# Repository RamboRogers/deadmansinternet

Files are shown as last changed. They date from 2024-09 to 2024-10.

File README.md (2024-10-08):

# Deadman's Internet

<p align="center">
  Full View
</p>

### A project by Matthew Rogers

Welcome to the **Deadman's Internet** project! My name is Matthew Rogers, and I'm passionate about creating practical, cost-effective solutions that solve real-world problems. You can learn more about my work on my [homepage](https://matthewrogers.org) or check out my other projects on my [GitHub profile](https://github.com/RamboRogers).

### Introduction

**Deadman's Internet** is a self-healing internet switch designed to ensure continuous connectivity by automatically resetting your network devices when a connection failure is detected. This project is ideal for anyone who experiences unreliable internet connections and wants a hands-off solution that keeps their network running smoothly without manual intervention.

The project is built around the affordable and powerful M5Stack AtomS3, making it both effective and budget-friendly, with a total cost of under $35.
| Online | Pinging | Cycling | Offline |
| --- | --- | --- | --- |
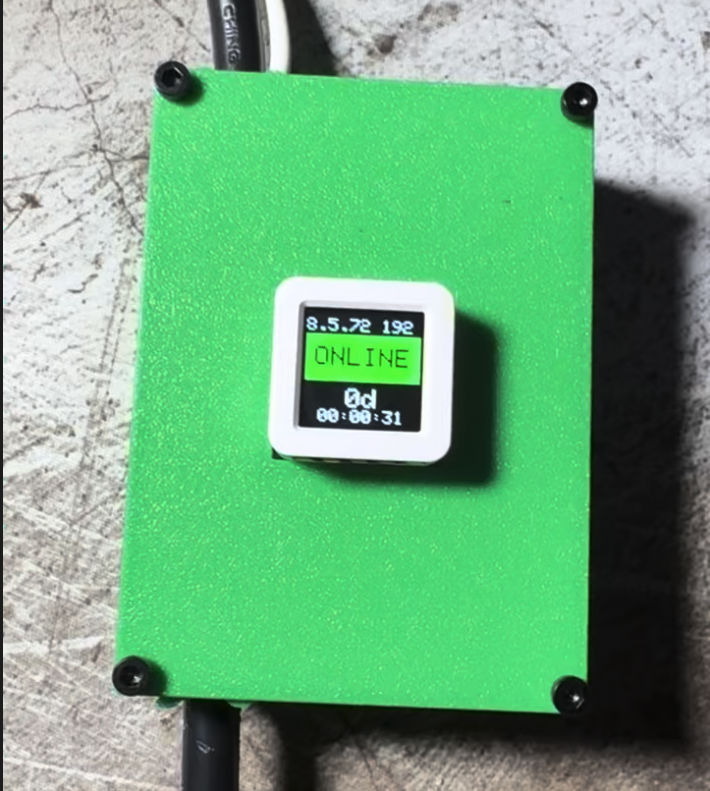
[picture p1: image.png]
Online
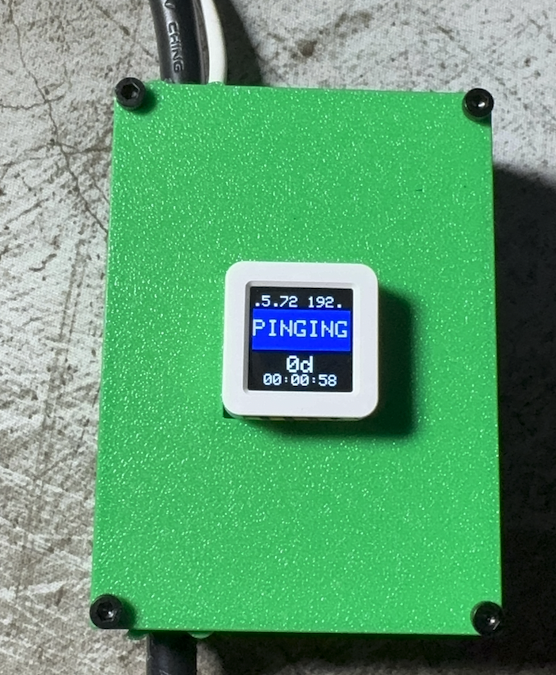
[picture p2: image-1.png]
Pinging
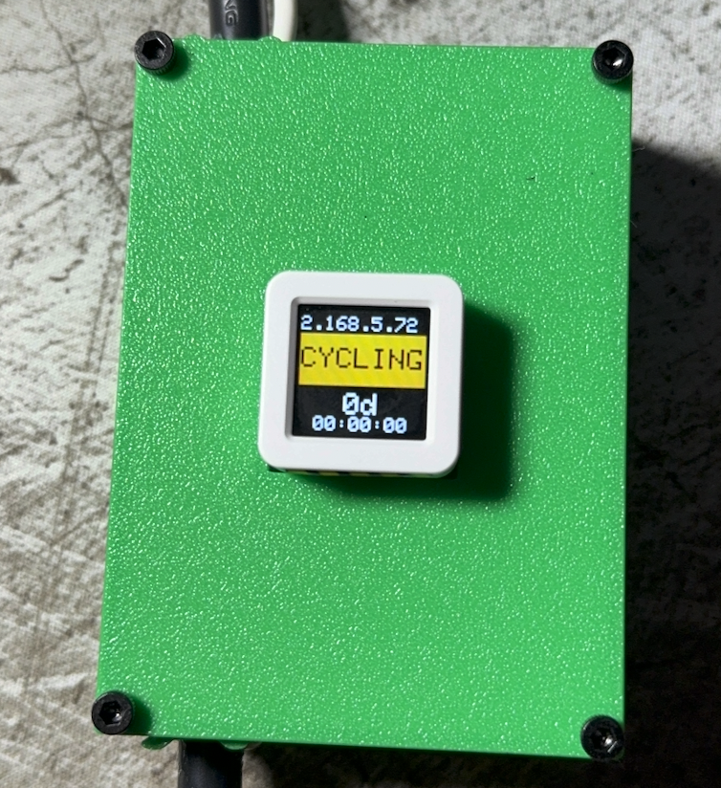
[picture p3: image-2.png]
Cycling
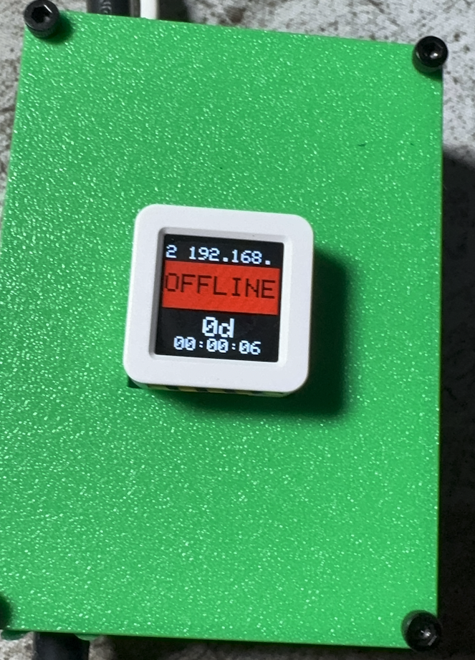
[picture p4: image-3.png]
Offline
|  |  |  |  |

The Enclosure is a 3D printed relay box. I designed it in Fusion 360, and printed it on my Bambu P1S.
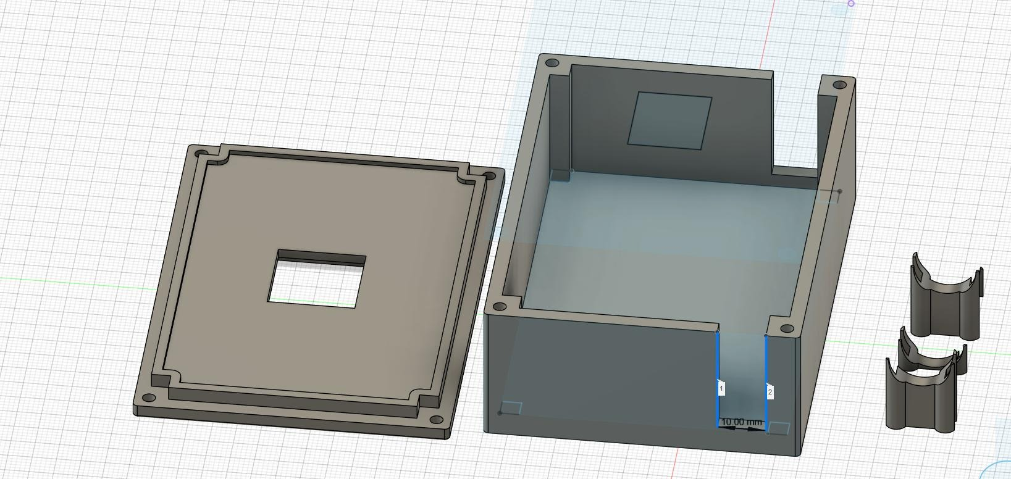
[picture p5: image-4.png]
Enclosure


### Features

- **Automatic Internet Recovery**: Monitors your network and automatically resets the connection if a failure is detected.
- **Real-Time Status Display**: Includes a built-in display that shows the current network status, uptime, and IP address.
- **Self-Reliant**: Functions independently, ensuring your internet connection recovers even when you're not present.
- **Web Interface**: Access the device's status and controls via a user-friendly web interface.
- **JSON API**: Retrieve detailed status information in JSON format via the `/data` endpoint.
- **Remote Reboot**: Ability to reboot the device remotely via the web interface.
- **Force Offline**: Option to force the device offline for testing or maintenance purposes.
- **Auto-Reboot**: The device will automatically reboot after 60 minutes of continuous internet issues.
- **Cost-Effective**: The entire project can be built for less than $35, using easily obtainable components.
- **Customizable**: The code is open-source and easily modifiable to suit different network environments or requirements.

### Hardware

To build the **Deadman's Internet** project, you will need the following hardware:

- [M5Stack AtomS3](https://shop.m5stack.com/products/atoms3-dev-kit-w-0-85-inch-screen): The core microcontroller that drives the project.
- [4-Relay Module](https://www.elegoo.com/products/elegoo-8-channel-relay-module-kit?variant=32467576356912): Allows the device to control power to your network equipment.
- [3D Printed Enclosure](PrintReady-RelayBoxv6.3mf): Protects the hardware and provides a neat, professional finish.
- [M3 Bolts](https://www.amazon.com/Metric-Screws-Suitable-Printer-Assortment/dp/B0B51BFSWZ/): Used to assemble the enclosure.
- [Male to Female Dupont Wires](https://www.amazon.com/California-JOS-Breadboard-Optional-Multicolored/dp/B0BRTHR2RL/): For connecting the components together.

**Total Cost**: Less than $35

### Setup and Installation

1. **Assemble the Hardware**: Connect the M5Stack AtomS3 to the 4-relay module according to the provided wiring diagram. Secure everything in the 3D printed enclosure using the M3 bolts. Wiring wise you'll connect the 4-relay module to the AtomS3 like so in the picture below. G5 and G6 are connected to the IN1 and IN2 of the relay module. You can use any GPIO pins you'd like, just make sure to change the code accordingly. The enclosure is sized perfectly with the M5Stack AtomS3 and the 4-relay module so the AtomS3 will snap right into it without any modifications or need to glue it in.

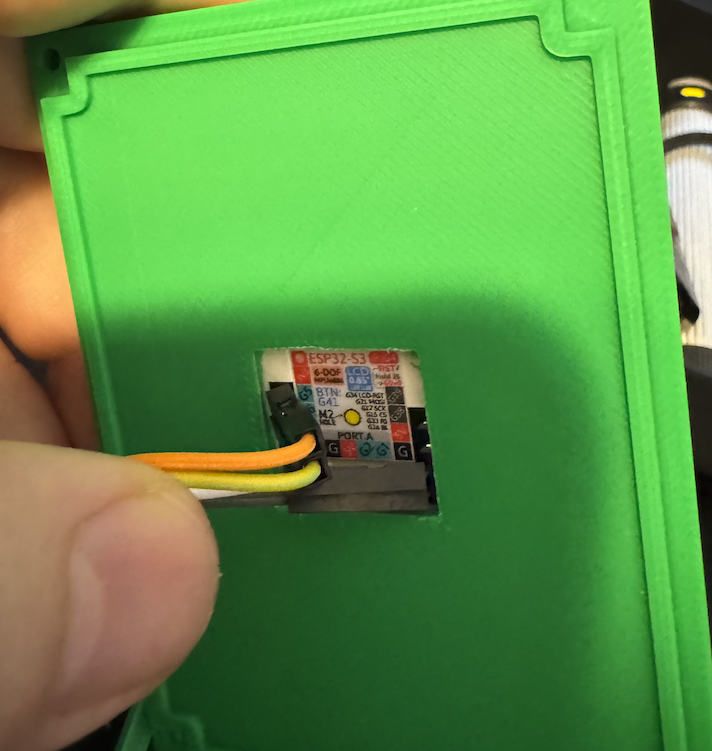
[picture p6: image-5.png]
Wiring


2. **Upload the Code**: Clone the repository and upload the provided code to the AtomS3 using PlatformIO. Ensure you have the necessary libraries installed. Make sure to put your wifi credentials into the code.

3. **Configure Your Network**: Modify the code to include your Wi-Fi credentials and any other specific settings for your network environment.

4. **Deploy**: Once everything is configured and the code is running, the **Deadman's Internet** device will begin monitoring your connection and automatically reset it as needed. Just plug in your router and ONT and plug the device into power. Right now it pings 8.8.8.8, but you can change that to any IP address you'd like.

### Web Interface and JSON API

**Deadman's Internet** provides a user-friendly web interface for monitoring and controlling the device:

- **Web Interface**: Access the current status and controls by navigating to the device's IP address in your web browser.
- **JSON API**: For more detailed status information, access the JSON API available at `/data`. This API provides data such as connection status, uptime, and the device's IP address in a structured format suitable for integration with other systems.

**Web GUI**

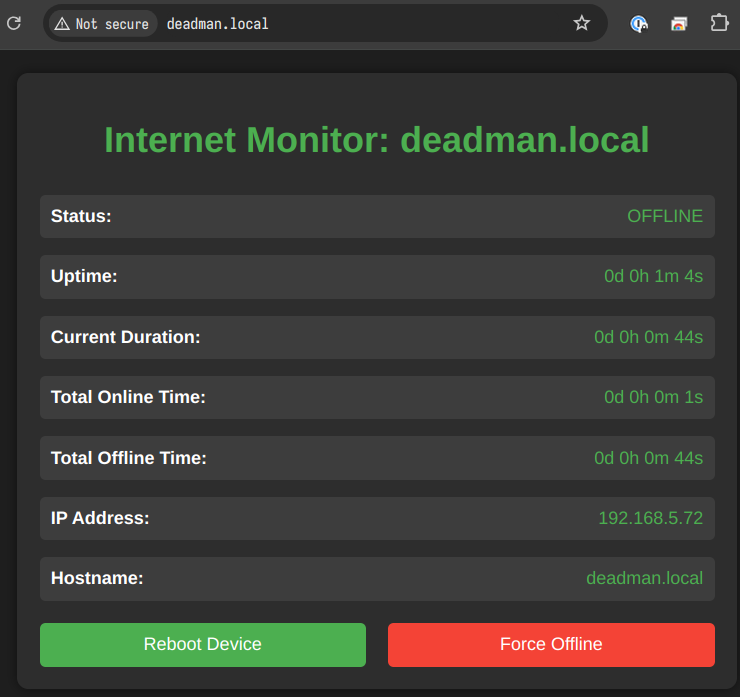
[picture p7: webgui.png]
webgui


**JSON API**

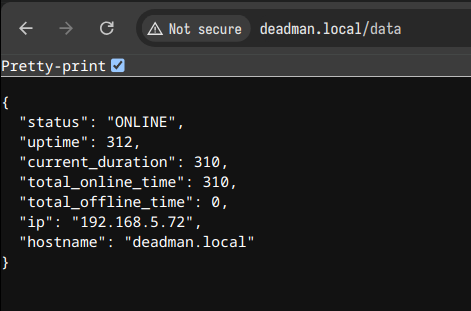
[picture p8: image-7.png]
jsonapi


### Usage

Once deployed, **Deadman's Internet** will monitor your network connection continuously. If it detects that the connection is lost, it will automatically reset the connected devices by toggling the relay module. The status of the connection and the uptime will be displayed on the AtomS3's screen and the web interface.

You can use the web interface to:
- View real-time status information
- Reboot the device remotely
- Force the device offline for testing or maintenance

### Recent Updates 2024-10-06

- Switched from Arduino IDE to PlatformIO for improved development workflow and dependency management.
- Added a remote reboot feature accessible via the web interface.
- Implemented a "Force Offline" function for testing and maintenance purposes.
- Added an auto-reboot feature that triggers after 60 minutes of continuous internet issues.
- Updated the web interface with new controls for reboot and force offline functions.
- Updated the endpoint to /data instead of /api and moved to seconds as a unit of measurement to allow easier charting.
- Add mDNS to the project to allow easier discovery.

### Recent Updates 2024-10-06
 
 - Discovered that the wifi was not reconnecting properly so added reconnect functionality.

### Future Enhancements

- **Customization**: The project is open-source, and contributions are welcome! Feel free to fork the repository and add your improvements.

### Contributing

If you have any ideas for enhancing the project or find any issues, feel free to open an issue or submit a pull request on the [GitHub repository](https://github.com/RamboRogers/Deadmans-Internet).

### License

This project is licensed under the MIT License - see the LICENSE file for details.

---

Thank you for your interest in the Deadman's Internet project. We're constantly working to improve and expand its capabilities. Stay tuned for more updates!

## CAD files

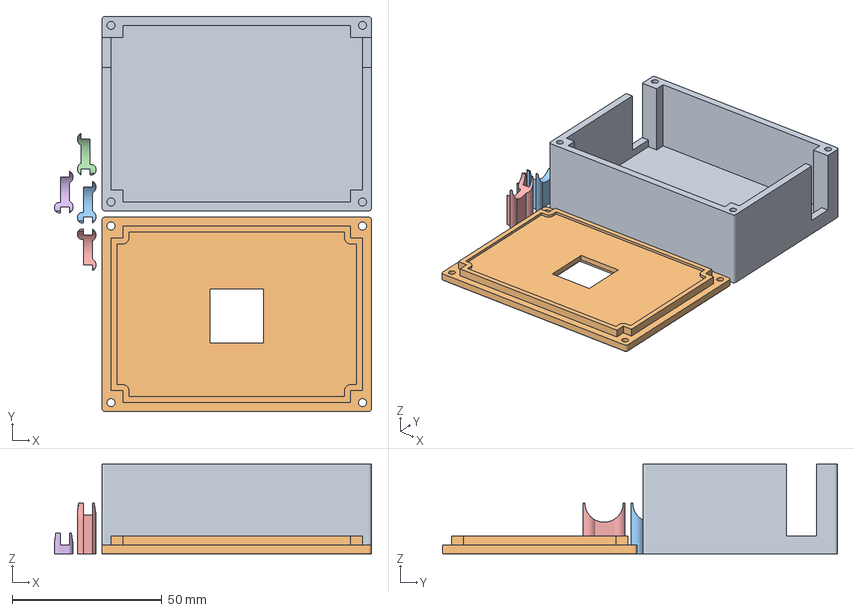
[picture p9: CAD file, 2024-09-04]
PrintReady-deadmansinternet.3mf
105.9 x 132.0 x 30.0 mm

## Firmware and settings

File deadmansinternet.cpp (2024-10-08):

#include <Arduino.h>
#include <WiFi.h>
#include <NTPClient.h>
#include <WiFiUdp.h>
#include <ESPping.h>
#include <M5AtomS3.h>
#include <ESPmDNS.h> // Add this line for mDNS support

//TODO

//Offline timer isn't trigger full failure or secondary repower
// Test with UDM
// 4/5 pings fail and it stays online..... lets give it another minute

// Pin Definitions
#define RELAY1 5 // G5 -> IN1
#define RELAY2 6 // G6 -> IN2

// WiFi Credentials
const char* ssid = "YOURSSID";
const char* password = "YOURPASSWORD";

// NTP Settings
const long utcOffsetInSeconds = -18000; // UTC -5 hours for Eastern Time
const char* ntpServer = "pool.ntp.org";
WiFiUDP ntpUDP;
NTPClient timeClient(ntpUDP, ntpServer, utcOffsetInSeconds);

// HTTP Server Setup
WiFiServer server(80);

// Time Tracking Variables
unsigned long previousPingMillis = 0;
const unsigned long pingInterval = 60000; // Ping every 1 minute

unsigned long onlineStartMillis = 0;
unsigned long offlineStartMillis = 0;
bool isOffline = false;

// Scrolling IP variables
String scrollingIP = "";
int scrollPosition = 0;
unsigned long lastScrollTime = 0;
const int scrollSpeed = 100; // Milliseconds between each scroll step

// Function Prototypes
void connectToWiFi();
void initializeRelays();
void updateDisplay();
void performPingCheck();
void handleClientRequests();
String formatDurationDays(unsigned long milliseconds);
String formatDurationHMS(unsigned long milliseconds);
void logStatus(const String& message);
void updateScrollingIP();
void setupMDNS();
String getMetricsJSON();
bool verifyWiFiConnection();


//Display on Screen CYCLING
void displayCycling() {
    // Increase the height of the green box by 75% (midpoint between 50% and 100%)
    int boxHeight = 53; // Original 30 * 1.75
    int boxTop = AtomS3.Display.height() / 2 - boxHeight * 3 / 4; // Move up from midpoint

    AtomS3.Display.setTextColor(BLACK, ORANGE);
    AtomS3.Display.fillRect(0, boxTop, AtomS3.Display.width(), boxHeight, ORANGE);

    // Increase text size and adjust position
    AtomS3.Display.setTextSize(3);
    AtomS3.Display.setTextDatum(MC_DATUM);
    AtomS3.Display.drawString("CYCLING", AtomS3.Display.width() / 2, boxTop + boxHeight / 2);

}

void checkButtonPress() {
    AtomS3.update();
    if (AtomS3.BtnA.wasPressed()) {
        logStatus("Button pressed. Forcing device to OFFLINE mode.");
      updateScrollingIP();
      updateDisplay();
      handleClientRequests();

            isOffline = true;
            offlineStartMillis = millis();
            logStatus("Switching to OFFLINE mode and restarting network devices.");
            updateScrollingIP();
            updateDisplay();
            handleClientRequests();
            // Activate Relays to Restart Devices
            digitalWrite(RELAY1, LOW);
            digitalWrite(RELAY2, LOW);
            logStatus("Relays activated. Restarting devices...");

            for (int i = 0; i < 30; i++) {
                // Update the display every second
                displayCycling();  // Call your display update function

                // Perform a delay for 1 second
                delay(1000);  // Delay for 1 second (1000 milliseconds)
            }

            digitalWrite(RELAY1, HIGH);
            digitalWrite(RELAY2, HIGH);
            logStatus("Relays deactivated.");

    }
}

void buttonPress() {
      logStatus("GUI Button pressed. Forcing device to OFFLINE mode.");
      updateScrollingIP();
      updateDisplay();
      handleClientRequests();

      isOffline = true;
      offlineStartMillis = millis();
      logStatus("Switching to OFFLINE mode and restarting network devices.");
      updateScrollingIP();
      updateDisplay();
      handleClientRequests();
      // Activate Relays to Restart Devices
      digitalWrite(RELAY1, LOW);
      digitalWrite(RELAY2, LOW);
      logStatus("Relays activated. Restarting devices...");

      for (int i = 0; i < 30; i++) {
          // Update the display every second
          displayCycling();  // Call your display update function

          // Perform a delay for 1 second
          delay(1000);  // Delay for 1 second (1000 milliseconds)
      }

      digitalWrite(RELAY1, HIGH);
      digitalWrite(RELAY2, HIGH);
      logStatus("Relays deactivated.");

    }

void setup() {
  Serial.begin(115200);
  delay(100);

  AtomS3.begin();
  AtomS3.Display.setBrightness(50);
  AtomS3.Display.setTextSize(1);
  AtomS3.Display.setTextColor(WHITE, BLACK);
  AtomS3.Display.fillScreen(BLACK);

  logStatus("System initializing...");

  initializeRelays();
  connectToWiFi();

  logStatus("Initializing NTP client...");
  timeClient.begin();
  if (timeClient.update()) {
    logStatus("NTP time synchronized.");
  } else {
    logStatus("Failed to synchronize NTP time.");
  }

  setupMDNS();
  
  server.begin();
  logStatus("HTTP server started.");

  onlineStartMillis = millis();
  scrollingIP = WiFi.localIP().toString() + " "; // Add some spaces for smooth scrolling
  updateDisplay();
}

unsigned long previousDisplayUpdateMillis = 0;
const unsigned long displayUpdateInterval = 1000; // Faster updates for smoother scrolling

unsigned long lastResetTime = 0;
const unsigned long REBOOT_THRESHOLD = 60 * 60 * 1000; // 60 minutes in milliseconds

//////Primary Loop
void loop() {
    checkButtonPress();

    unsigned long currentMillis = millis();

    if (currentMillis - previousPingMillis >= pingInterval) {
        previousPingMillis = currentMillis;
        performPingCheck();
    }

    if (currentMillis - previousDisplayUpdateMillis >= displayUpdateInterval) {
        previousDisplayUpdateMillis = currentMillis;
        updateScrollingIP();
        updateDisplay();
    }

    handleClientRequests();

    // Check if we need to reboot after 60 minutes of continuous resets
    if (millis() - lastResetTime > REBOOT_THRESHOLD) {
        logStatus("60 minutes of continuous resets. Rebooting device.");
        ESP.restart();
    }
}

void connectToWiFi() {
  logStatus("Connecting to WiFi...");
  AtomS3.Display.fillScreen(BLUE);
  AtomS3.Display.setCursor(10, 20);
  AtomS3.Display.setTextSize(2); // Keep text size at 2
  AtomS3.Display.print("Connecting to WiFi...");

  WiFi.begin(ssid, password);

  int retryCount = 0;
  while (WiFi.status() != WL_CONNECTED && retryCount < 20) {
    delay(1000);
    AtomS3.Display.print(".");
    retryCount++;
    Serial.print(".");
  }

  if (WiFi.status() == WL_CONNECTED) {
    logStatus("Connected to WiFi.");
    logStatus("IP Address: " + WiFi.localIP().toString());
  } else {
    logStatus("Failed to connect to WiFi.");
    AtomS3.Display.fillScreen(RED);
    AtomS3.Display.setCursor(10, 20);
    AtomS3.Display.print("WiFi Connection Failed!");
  }
}

void initializeRelays() {
  logStatus("Initializing relays...");
  pinMode(RELAY1, OUTPUT);
  pinMode(RELAY2, OUTPUT);
  digitalWrite(RELAY1, HIGH);
  digitalWrite(RELAY2, HIGH);
  logStatus("Relays initialized and set to OFF.");
}

void updateScrollingIP() {
  if (millis() - lastScrollTime > scrollSpeed) {
    lastScrollTime = millis();
    scrollPosition++;
    if (scrollPosition >= scrollingIP.length()) {
      scrollPosition = 0;
    }
  }
}

void updateDisplay() {
  AtomS3.Display.fillScreen(BLACK);

  // Calculate the position for the IP address
  int boxHeight = 53; // Height of the green box
  int boxTop = AtomS3.Display.height() / 2 - boxHeight * 3 / 4; // Top of the green box
  int ipY = boxTop * 0.6; // Move IP down by 60% of the space above the green box

  // Display Scrolling IP Address
  AtomS3.Display.setTextSize(2); // Keep text size at 2
  AtomS3.Display.setTextColor(WHITE, BLACK);
  AtomS3.Display.setCursor(0, ipY);
  String visibleIP = scrollingIP.substring(scrollPosition) + scrollingIP.substring(0, scrollPosition);
  visibleIP = visibleIP.substring(0, 10); // Keep substring size at 10
  AtomS3.Display.print(visibleIP);

  // Display Connection Status and Duration
  if (isOffline) {
    unsigned long offlineDuration = millis() - offlineStartMillis;

    // Increase the height of the red box by 75% (midpoint between 50% and 100%)
    int boxHeight = 53; // Original 30 * 1.75
    int boxTop = AtomS3.Display.height() / 2 - boxHeight * 3 / 4; // Move up from midpoint

    AtomS3.Display.setTextColor(BLACK, RED);
    AtomS3.Display.fillRect(0, boxTop, AtomS3.Display.width(), boxHeight, RED);

    // Increase text size and adjust position
    AtomS3.Display.setTextSize(3);
    AtomS3.Display.setTextDatum(MC_DATUM);
    AtomS3.Display.drawString("OFFLINE", AtomS3.Display.width() / 2, boxTop + boxHeight / 2);

    // Center and increase size of duration information
    AtomS3.Display.setTextColor(WHITE, BLACK);

    // Display days with larger text size
    AtomS3.Display.setTextSize(3);
    String daysText = formatDurationDays(offlineDuration);
    AtomS3.Display.setTextDatum(CC_DATUM);
    AtomS3.Display.drawString(daysText, AtomS3.Display.width() / 2, AtomS3.Display.height() - 30);

    // Display time with slightly smaller text size
    AtomS3.Display.setTextSize(2);
    String timeText = formatDurationHMS(offlineDuration);
    AtomS3.Display.drawString(timeText, AtomS3.Display.width() / 2, AtomS3.Display.height() - 10);
  } else {
    unsigned long onlineDuration = millis() - onlineStartMillis;

    // Increase the height of the green box by 75% (midpoint between 50% and 100%)
    int boxHeight = 53; // Original 30 * 1.75
    int boxTop = AtomS3.Display.height() / 2 - boxHeight * 3 / 4; // Move up from midpoint

    AtomS3.Display.setTextColor(BLACK, GREEN);
    AtomS3.Display.fillRect(0, boxTop, AtomS3.Display.width(), boxHeight, GREEN);

    // Increase text size and adjust position
    AtomS3.Display.setTextSize(3);
    AtomS3.Display.setTextDatum(MC_DATUM);
    AtomS3.Display.drawString("ONLINE", AtomS3.Display.width() / 2, boxTop + boxHeight / 2);

    // Center and increase size of duration information
    AtomS3.Display.setTextColor(WHITE, BLACK);

    // Display days with larger text size
    AtomS3.Display.setTextSize(3);
    String daysText = formatDurationDays(onlineDuration);
    AtomS3.Display.setTextDatum(CC_DATUM);
    AtomS3.Display.drawString(daysText, AtomS3.Display.width() / 2, AtomS3.Display.height() - 30);

    // Display time with slightly smaller text size
    AtomS3.Display.setTextSize(2);
    String timeText = formatDurationHMS(onlineDuration);
    AtomS3.Display.drawString(timeText, AtomS3.Display.width() / 2, AtomS3.Display.height() - 10);
  }
}



//Display on Screen PINGING
void displayPinging() {
    // Increase the height of the green box by 75% (midpoint between 50% and 100%)
    int boxHeight = 53; // Original 30 * 1.75
    int boxTop = AtomS3.Display.height() / 2 - boxHeight * 3 / 4; // Move up from midpoint

    AtomS3.Display.setTextColor(WHITE, BLUE);
    AtomS3.Display.fillRect(0, boxTop, AtomS3.Display.width(), boxHeight, BLUE);

    // Increase text size and adjust position
    AtomS3.Display.setTextSize(3);
    AtomS3.Display.setTextDatum(MC_DATUM);
    AtomS3.Display.drawString("PINGING", AtomS3.Display.width() / 2, boxTop + boxHeight / 2);

}

//TODO: This function is locking up the screen.  We need to fix
unsigned long lastRelayActionTime = 0; // Global variable to track the last relay action time

// Add this function near the other WiFi-related functions
bool verifyWiFiConnection() {
  if (WiFi.status() != WL_CONNECTED) {
    logStatus("WiFi connection lost. Attempting to reconnect...");
    WiFi.disconnect();
    delay(1000);
    WiFi.begin(ssid, password);
    
    int attempts = 0;
    while (WiFi.status() != WL_CONNECTED && attempts < 20) {
      delay(500);
      logStatus("Reconnecting to WiFi...");
      attempts++;
    }
    
    if (WiFi.status() == WL_CONNECTED) {
      logStatus("WiFi reconnected successfully.");
      scrollingIP = WiFi.localIP().toString() + " ";
      return true;
    } else {
      logStatus("Failed to reconnect to WiFi.");
      return false;
    }
  }
  return true;
}

// Update the performPingCheck function to use verifyWiFiConnection
void performPingCheck() {
  logStatus("Performing ping check...");
  
  // First, verify WiFi connection
  if (!verifyWiFiConnection()) {
    logStatus("Cannot perform ping check due to WiFi disconnection.");
    isOffline = true;
    offlineStartMillis = millis();
    updateScrollingIP();
    updateDisplay();
    handleClientRequests();
    return;
  }
  
  int successCount = 0;
  for (int i = 0; i < 5; i++) {
    updateScrollingIP();
    displayPinging();
    handleClientRequests();
    checkButtonPress();
    if (Ping.ping("8.8.8.8")) {
      successCount++;
      logStatus("Ping " + String(i+1) + ": Success");
    } else {
      logStatus("Ping " + String(i+1) + ": Failure");
    }
    updateScrollingIP();
    displayPinging();
    handleClientRequests();
    checkButtonPress();
  }

  unsigned long currentTime = millis();
  bool fiveMinutesPassed = (currentTime - lastRelayActionTime) >= 300000; // 300000 ms = 5 minutes

  if (successCount > 0) {
    if (isOffline) {
      logStatus("Internet connection restored. Switching to ONLINE mode.");
      isOffline = false;
      onlineStartMillis = currentTime;
      lastRelayActionTime = currentTime; // Reset the timer when coming back online
    } else {
      logStatus("Internet connection is stable.");
    }
    updateScrollingIP();
    updateDisplay();
    handleClientRequests();
  } else {
    if (!isOffline) {
      logStatus("All pings failed. Switching to OFFLINE mode.");
      isOffline = true;
      offlineStartMillis = currentTime;
      lastRelayActionTime = currentTime;
    } else if (fiveMinutesPassed) {
      logStatus("5 minutes passed while offline. Restarting network devices.");
      lastRelayActionTime = currentTime;
      lastResetTime = currentTime; // Update the last reset time
      
      // Activate Relays to Restart Devices
      digitalWrite(RELAY1, LOW);
      digitalWrite(RELAY2, LOW);

      //30 second power down
      logStatus("Relays activated. Restarting devices...");
      for (int i = 0; i < 30; i++) {
        displayCycling();
        delay(1000);
      }
      digitalWrite(RELAY1, HIGH);
      digitalWrite(RELAY2, HIGH);
      logStatus("Relays deactivated.");
    } else {
      logStatus("Still offline. Monitoring continues.");
    }
  }
  
  updateScrollingIP();
  updateDisplay();
  handleClientRequests();
}

const char INDEX_HTML[] PROGMEM = R"rawliteral(
<!DOCTYPE HTML>
<html>
<head>
  <meta name="viewport" content="width=device-width, initial-scale=1">
  <style>
    body {
      font-family: Arial, sans-serif;
      background-color: #1e1e1e;
      color: #ffffff;
      margin: 0;
      padding: 20px;
    }
    .container {
      max-width: 600px;
      margin: 0 auto;
      background-color: #2d2d2d;
      border-radius: 10px;
      padding: 20px;
      box-shadow: 0 0 10px rgba(0,0,0,0.5);
    }
    h1 {
      color: #4CAF50;
      text-align: center;
      margin-bottom: 30px;
    }
    .data-row {
      display: flex;
      justify-content: space-between;
      margin-bottom: 15px;
      padding: 10px;
      background-color: #3d3d3d;
      border-radius: 5px;
    }
    .label {
      font-weight: bold;
    }
    .value {
      color: #4CAF50;
    }
    .button-container {
      display: flex;
      justify-content: space-between;
      margin-top: 20px;
    }
    .button {
      flex: 1;
      padding: 10px;
      color: white;
      border: none;
      border-radius: 5px;
      font-size: 16px;
      cursor: pointer;
      transition: background-color 0.3s;
    }
    .reboot-button {
      background-color: #4CAF50;
      margin-right: 10px;
    }
    .reboot-button:hover {
      background-color: #45a049;
    }
    .force-offline-button {
      background-color: #f44336;
      margin-left: 10px;
    }
    .force-offline-button:hover {
      background-color: #d32f2f;
    }
  </style>
  <script>
    function updateData() {
      fetch('/data')
        .then(response => response.json())
        .then(data => {
          document.getElementById('status').textContent = data.status;
          document.getElementById('uptime').textContent = formatDuration(data.uptime);
          document.getElementById('currentDuration').textContent = formatDuration(data.current_duration);
          document.getElementById('totalOnlineTime').textContent = formatDuration(data.total_online_time);
          document.getElementById('totalOfflineTime').textContent = formatDuration(data.total_offline_time);
          document.getElementById('ip').textContent = data.ip;
          document.getElementById('hostname').textContent = data.hostname;
        });
    }
    function formatDuration(seconds) {
      let minutes = Math.floor(seconds / 60);
      let hours = Math.floor(minutes / 60);
      let days = Math.floor(hours / 24);
      
      return `${days}d ${hours%24}h ${minutes%60}m ${seconds%60}s`;
    }
    function rebootDevice() {
      if (confirm('Are you sure you want to reboot the device?')) {
        fetch('/reboot')
          .then(response => response.json())
          .then(data => {
            alert('Device is rebooting. Please wait a moment before refreshing the page.');
          })
          .catch(error => {
            console.error('Error:', error);
            alert('An error occurred while trying to reboot the device.');
          });
      }
    }
    function forceOffline() {
      if (confirm('Are you sure you want to force the device offline?')) {
        fetch('/forceoffline')
          .then(response => response.json())
          .then(data => {
            alert('Device is being forced offline. The status will update shortly.');
          })
          .catch(error => {
            console.error('Error:', error);
            alert('An error occurred while trying to force the device offline.');
          });
      }
    }
    setInterval(updateData, 5000);  // Update every 5 seconds
  </script>
</head>
<body onload="updateData()">
  <div class="container">
    <h1>Internet Monitor: %HOSTNAME%</h1>
    <div class="data-row">
      <span class="label">Status:</span>
      <span class="value" id="status">--</span>
    </div>
    <div class="data-row">
      <span class="label">Uptime:</span>
      <span class="value" id="uptime">--</span>
    </div>
    <div class="data-row">
      <span class="label">Current Duration:</span>
      <span class="value" id="currentDuration">--</span>
    </div>
    <div class="data-row">
      <span class="label">Total Online Time:</span>
      <span class="value" id="totalOnlineTime">--</span>
    </div>
    <div class="data-row">
      <span class="label">Total Offline Time:</span>
      <span class="value" id="totalOfflineTime">--</span>
    </div>
    <div class="data-row">
      <span class="label">IP Address:</span>
      <span class="value" id="ip">--</span>
    </div>
    <div class="data-row">
      <span class="label">Hostname:</span>
      <span class="value" id="hostname">--</span>
    </div>
    <div class="button-container">
      <button class="button reboot-button" onclick="rebootDevice()">Reboot Device</button>
      <button class="button force-offline-button" onclick="forceOffline()">Force Offline</button>
    </div>
  </div>
</body>
</html>
)rawliteral";

void handleClientRequests() {
  WiFiClient client = server.available();
  if (client) {
    logStatus("Client connected.");
    String request = client.readStringUntil('\r');
    client.flush();

    String response;
    if (request.indexOf("/data") != -1) {
      // JSON endpoint for metrics
      client.println("HTTP/1.1 200 OK");
      client.println("Content-Type: application/json");
      client.println();
      response = getMetricsJSON();
    } else if (request.indexOf("/reboot") != -1) {
      // Reboot endpoint
      client.println("HTTP/1.1 200 OK");
      client.println("Content-Type: application/json");
      client.println();
      response = "{\"status\":\"rebooting\"}";
      client.print(response);
      client.stop();
      logStatus("Reboot requested via web endpoint.");
      delay(1000);  // Give some time for the response to be sent
      ESP.restart();  // Reboot the device
    } else if (request.indexOf("/forceoffline") != -1) {
      // Force offline endpoint
      client.println("HTTP/1.1 200 OK");
      client.println("Content-Type: application/json");
      client.println();
      response = "{\"status\":\"forcing offline\"}";
      client.print(response);
      client.stop();
      logStatus("Force offline requested via web endpoint.");
      buttonPress(); // Call the buttonPress routine
    } else {
      // HTML Response
      client.println("HTTP/1.1 200 OK");
      client.println("Content-Type: text/html");
      client.println();
      response = String(INDEX_HTML);
      response.replace("%HOSTNAME%", "deadman.local");
    }
    client.print(response);
    client.stop();
    logStatus("Response sent to client.");
  }
}

// Update formatDurationDays to return a more concise string
String formatDurationDays(unsigned long milliseconds) {
  unsigned long days = milliseconds / (1000 * 60 * 60 * 24);
  char buffer[10];
  sprintf(buffer, "%lud", days);
  return String(buffer);
}

String formatDurationHMS(unsigned long milliseconds) {
  unsigned long seconds = (milliseconds / 1000) % 60;
  unsigned long minutes = (milliseconds / (1000 * 60)) % 60;
  unsigned long hours = (milliseconds / (1000 * 60 * 60)) % 24;

  char buffer[20];
  sprintf(buffer, "%02lu:%02lu:%02lu", hours, minutes, seconds);
  return String(buffer);
}

void logStatus(const String& message) {
  String timestamp = timeClient.getFormattedTime();
  Serial.println("[" + timestamp + "] " + message);
}

void setupMDNS() {
  if (MDNS.begin("deadman")) {
    logStatus("mDNS responder started. Hostname: deadman.local");
    MDNS.addService("http", "tcp", 80);
  } else {
    logStatus("Error setting up mDNS responder!");
  }
}
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
